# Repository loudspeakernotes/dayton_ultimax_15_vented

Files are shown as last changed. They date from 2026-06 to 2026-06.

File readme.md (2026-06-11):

## Subwoofer Enclosure Design

Enclosure design for Dayton Ultimax 15 UMII15-22

General info for driver:
https://www.daytonaudio.com/product/2065/umii15-22-ultimax-ii-15-dvc-subwoofer-2-ohms-per-coil

Spec sheet for driver:
https://www.daytonaudio.com/images/resources/295-714--dayton-audio-UMII15-22-spec-sheet.pdf

Enclosure design is based on modelling in WinISD.

Overall box dimensions using 19mm ply/mdf is:
* 628mm wide
* 748mm deep
* 838mm tall

3D model of the enclosure can be viewed at [ultimax_15_vented_4_triangles.stl](ultimax_15_vented_4_triangles.stl)

OpenSCAD code for generating the model of the enclosure is in [ultimax_15_vented_4_triangles.scad](ultimax_15_vented_4_triangles.scad)

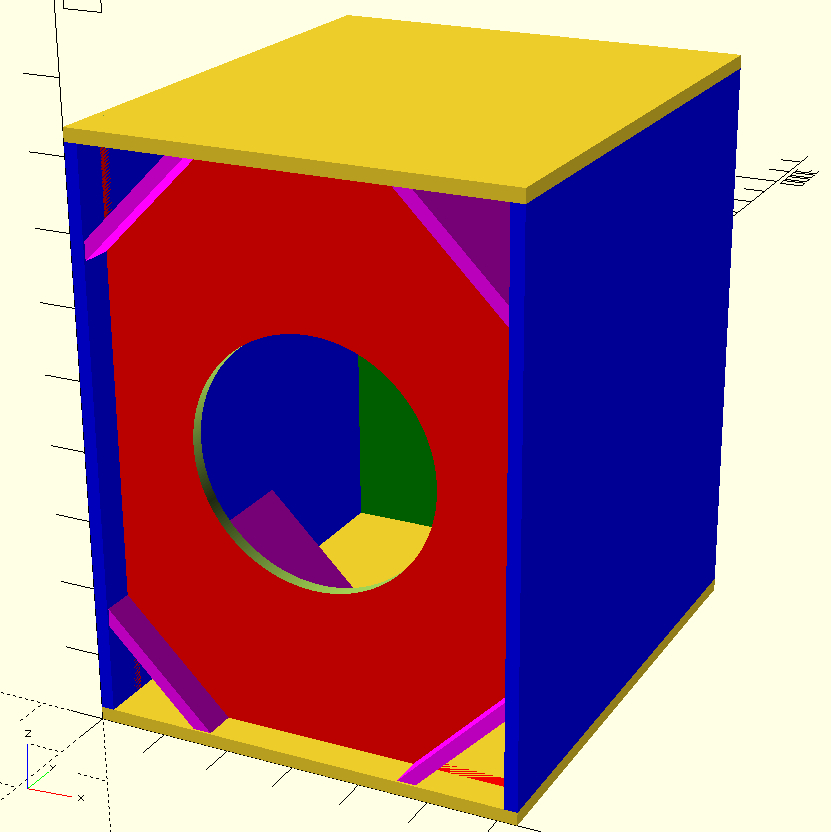
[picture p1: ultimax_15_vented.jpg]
Enclosure overview


## Panel sizes

For 19mm plywood

* Port panels x4: 443 x 217.605 - should be 179.605 wide on short side of bevel
* Bottom: 748 x 628
* Top: 748 x 628
* Side: 800 x 748
* Side: 800 x 748
* Front: 800 x 590
* Sub cutout diameter: 354
* Back: 800 x 590

Port panels should be cut with 45 degree bevel so the wide side of the piece is
217.6mm wide and the narrow side of the piece is 179.6mm wide. All ports are
443mm long.

Front panel is set back 50mm from the front to allow for a grill.

Extra bracing will help the stiffness of back, side, top, bottom panels.

Box air volume (not including ports, speaker): approx 302.093 litres

## Modelling

Using WinISD

Setup:

* 1 Driver
* Vented enclosure

Parameters:

* 300L box volume
* 25Hz port tuning
* 4 ports, square cross section, 9cm x 9cm (converted to equivalent triangles in this enclosure)
* 600W input signal

Metrics:

* Enclosure gain: 4.6 dB at 28.5 Hz
* -3db from peak of 4.6 dB at 22.29 Hz
* -3db at 19.89 Hz
* Peak SPL at 600W: 118 dB at 28.3 Hz
* Peak port air velocity: 23 m/s at 23 Hz
* Maximum cone excursion at 600W: 19.89 Hz

## Charts

Results from modelling in WinISD

### Transfer magnitude function

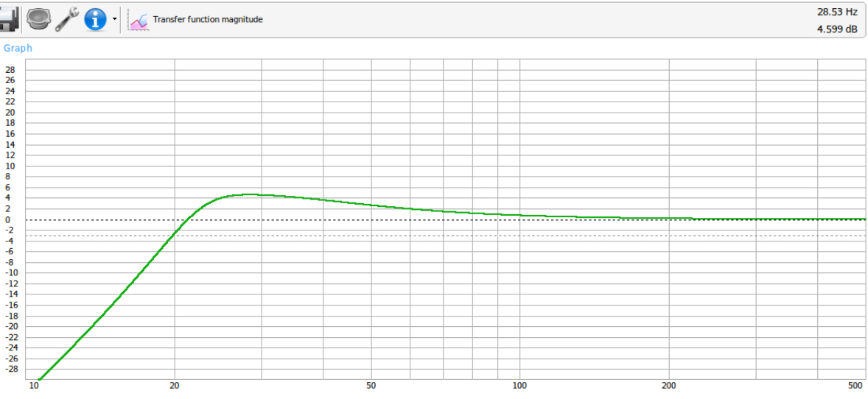
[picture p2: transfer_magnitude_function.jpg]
Transfer magnitude function


### SPL

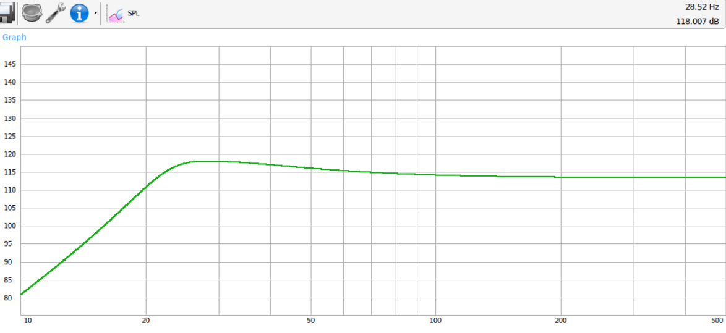
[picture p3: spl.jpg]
Sound pressure level


### Rear port air velocity

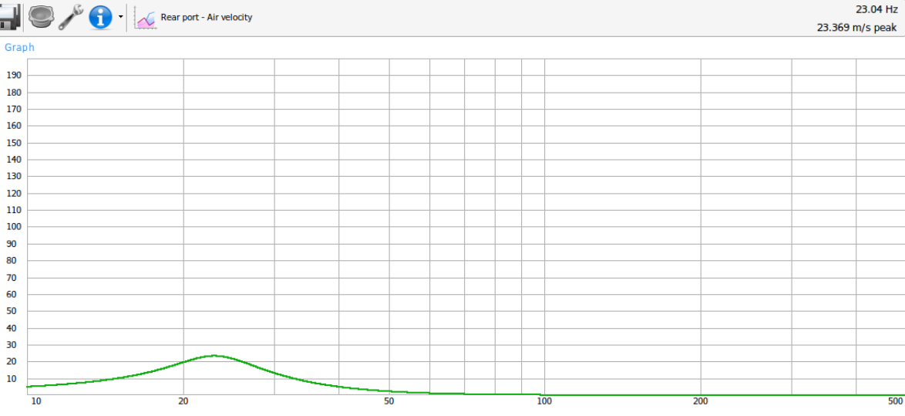
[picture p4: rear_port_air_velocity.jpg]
Rear port air velocity


### Group delay

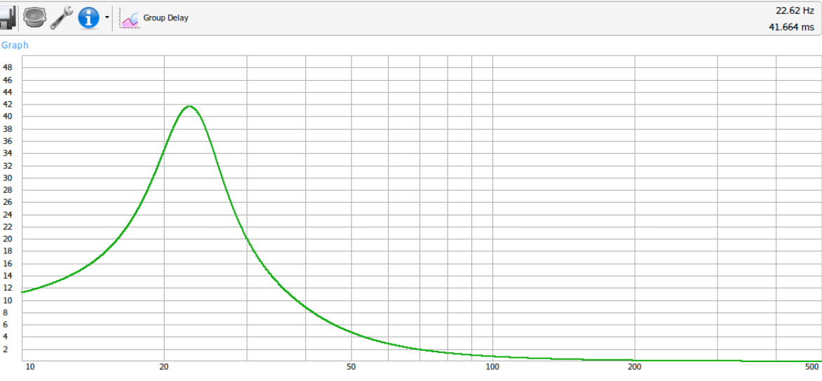
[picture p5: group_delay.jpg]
Group delay


### Cone excursion

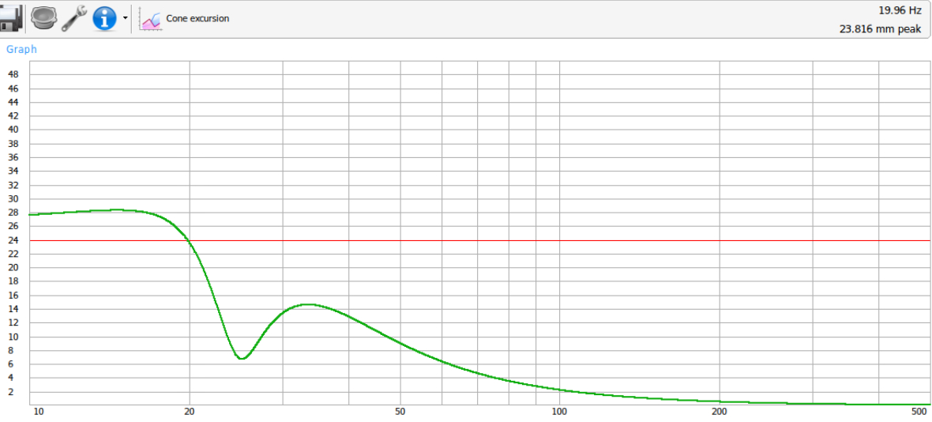
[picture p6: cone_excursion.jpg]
Cone excursion


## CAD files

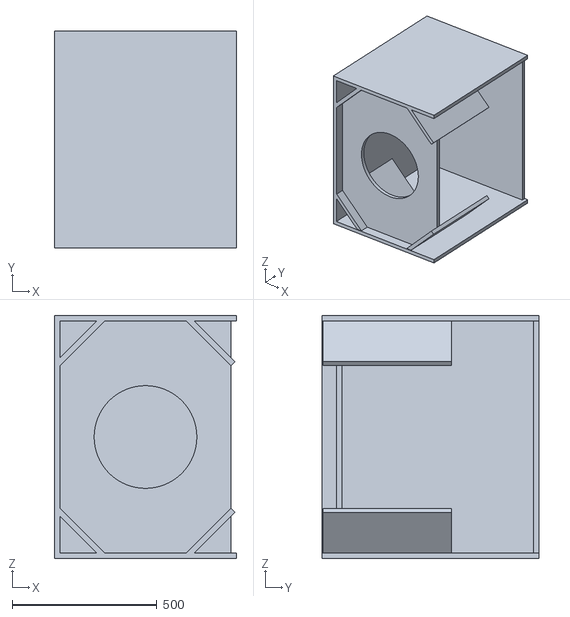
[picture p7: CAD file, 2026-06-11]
ultimax_15_vented_4_triangles.stl
628.0 x 748.0 x 838.0

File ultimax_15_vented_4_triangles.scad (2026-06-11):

// Basic vented box for Dayton Ultimax 15" subwoofer
// Modelled in WinISD

// Volume 300L (not including ports, speaker, stuffing
// Tuning 25Hz
// 4 ports triangle shaped
// Triangle port area equivalent to 9cm x 9cm square ports

// Max cone excursion at 600W happens at 20Hz
// Set highpass filter higher than 20Hz

iw = 590;
id = 710;
ih = 800;
t = 19;
front_setback = 50;


// each triangle port area is equivalent to 90x90mm square port
pl = 443; // port length
pis = 127; // port inner side length
pid = sqrt(pis*pis*2); // port inner diagonal length
echo(str("Port panels short width: ", pl, " x ", pid));
pos = pis+sqrt(t*t*2); // port outer side length
pod = sqrt(pos*pos*2); // port outer diagonal length
echo(str("Port panels long width: ", pl, " x ", pod));

// subwoofer details
// dayton ultimax 15 UMII15-22
// see spec sheet at https://www.daytonaudio.com/images/resources/295-714--dayton-audio-UMII15-22-spec-sheet.pdf
// and general info at
// https://www.daytonaudio.com/product/2065/umii15-22-ultimax-ii-15-dvc-subwoofer-2-ohms-per-coil

subd = 354;

// base
translate([0, 0, 0]) {
    w = t + iw + t;
    d = t + id + t;
    cube([w, d, t]);
    echo(str("Bottom: ", d, " x ", w));
}

// top
translate([0, 0, t+ih]) {
    w = t + iw + t;
    d = t + id + t;
    cube([w, d, t]);
    echo(str("Bottom: ", d, " x ", w));
}

// side
translate([0, 0, t]) {
    d = t + id + t;
    h = ih;
    color("blue") cube([t, d, h]);
    echo(str("Side: ", h, " x ", d));
}

// side
translate([t+iw, 0, t]) {
    d = t + id + t;
    h = ih;
    //color("blue") cube([t, d, h]);
    echo(str("Side: ", h, " x ", d));
}

// front
translate([t, front_setback, t]) {
    w = iw;
    h = ih;
    difference() {
        color("red") cube([w, t, h]);
        echo(str("Front: ", h, " x ", w));
        // port cutouts
        // bottom left
        translate([0, -1, pos]) {
            rotate([0, 90+45, 0]) {
                cube([1000, t+2, 1000]);
            }
        }
        // bottom right
        translate([iw-pos, -1, 0]) {
            rotate([0, 45, 0]) {
                cube([1000, t+2, 1000]);
            }
        }
        // top left
        translate([0, -1, ih-pos]) {
            rotate([0, -45, 0]) {
                cube([1000, t+2, 1000]);
            }
        }
        // top right
        translate([iw-pos, -1, ih]) {
            rotate([0, 45, 0]) {
                cube([1000, t+2, 1000]);
            }
        }
        // sub hole
        translate([iw/2, -1, ih/2]) {
            rotate([270, 0, 0]) {
                // cutout diameter 353mm +- 0.5
                cylinder(d=subd, h=t+2, $fn=300);
                echo(str("Sub cutout diameter: ", subd));
            }
        }
    }
}

// back
translate([t, t+id, t]) {
    w = iw;
    h = ih;
    color("green") cube([w, t, h]);
    echo(str("Back: ", h, " x ", w));
}



// ports
port_yoffset = 3;
// bottom left
translate([t-sqrt((t*t)/2), port_yoffset, t+pos-sqrt((t*t)/2)]) {
    rotate([0, 45, 0]) {
        color("magenta") cube([pod, pl, t]);
    }
}
// bottom right
translate([t, port_yoffset, t+ih-pos]) {
    rotate([0, -45, 0]) {
        color("magenta") cube([pod, pl, t]);
    }
}

// top right
translate([t+iw-pos, port_yoffset, t+ih]) {
    rotate([0, 45, 0]) {
        color("magenta") cube([pod, pl, t]);
    }
}

// bottom right
translate([t+iw-pos+sqrt((t*t)/2), port_yoffset, t-sqrt((t*t)/2)]) {
    rotate([0, -45, 0]) {
        color("magenta") cube([pod, pl, t]);
    }
}

// volume
subv = 5; // litres, as a guess
portv = pos*pos/2 * (pl-t-front_setback) / 1000000;
boxv = iw * (id-front_setback) * ih / 1000000;
v = boxv - subv - portv;
echo(str("Box volume: ", v, " litres"));
